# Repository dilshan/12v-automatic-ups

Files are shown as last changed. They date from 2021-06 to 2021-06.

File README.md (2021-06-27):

# 12V Uninterruptible Power Supply

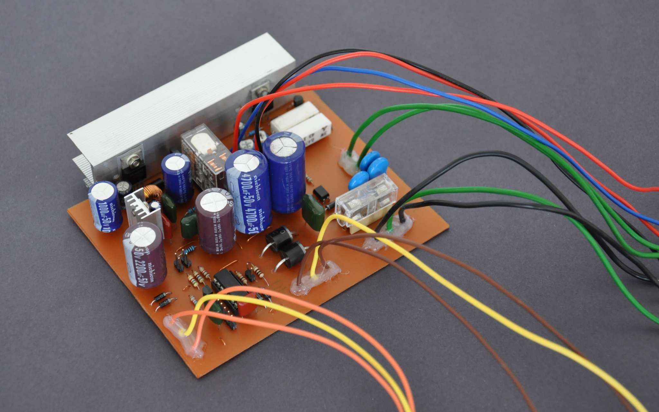
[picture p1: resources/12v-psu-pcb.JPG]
Prototype version of 12V UPS system


This 12V uninterruptible power supply initially designs to drive my fiber optic modem/router. The key reason to build this power supply is to get continuous internet and phone connection during power failures. Core components of this power supply are a constant voltage charger, 12V DC power supply, AC line monitoring unit, and 12V high capacity sealed lead-acid battery. The entire system designs using locally available components.

The charging circuit of this system builds around using the popular *[LM350](https://www.ti.com/lit/ds/snvs772b/snvs772b.pdf)* voltage regulator. This regulator calibrates to provide both 14.4V fast charging and 13.6V trickle charging. Based on the condition of the battery, the MCU will determine the appropriate charging mode.

At the online state, the *[LM2576-12](https://www.ti.com/lit/ds/symlink/lm2576.pdf)* switching regulator provides 12V output to the driving system. (in my arrangement, a fiber optic router).

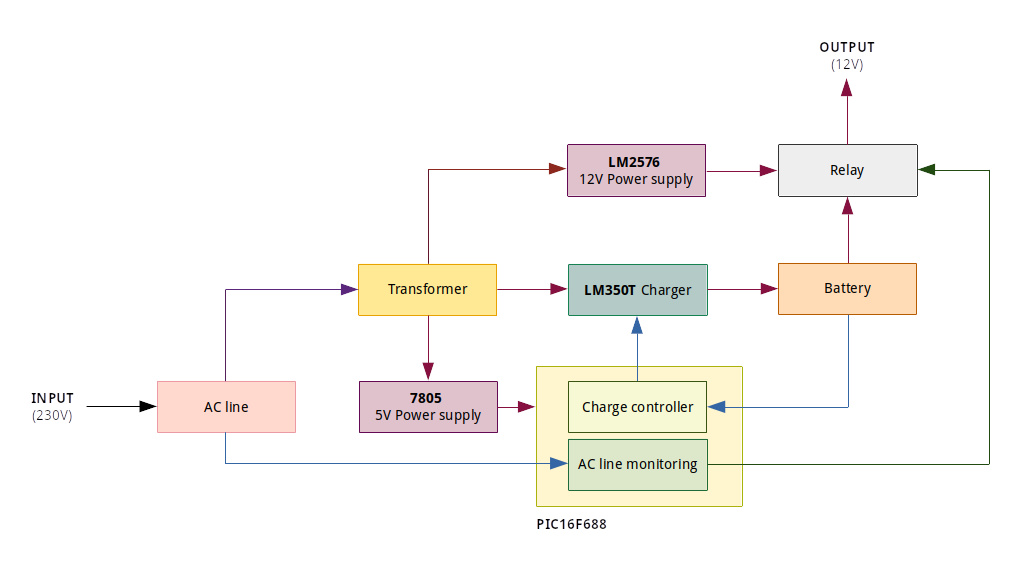
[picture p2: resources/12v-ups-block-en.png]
Block diagram of the UPS system


The *[PIC16F688](http://ww1.microchip.com/downloads/en/devicedoc/41203d.pdf)* MCU monitors the AC line and battery to controls the output voltage of the *LM350* regulator and the output relay. The firmware of this MCU written using the *[Microchip XC8](https://www.microchip.com/en-us/development-tools-tools-and-software/mplab-xc-compilers)* compiler, and all the source code and configuration files are available to [download](https://github.com/dilshan/12v-automatic-ups/releases) in this project repository.

The sealed 12V lead-acid battery is the most crucial component of this unit. 12V, 9Ah battery is the most recommended for this system. At the time of this writing, this battery cost around Rs. 3500 (US$ 17.60), and I bought it from a local online store.

In online mode, this system provides 12V output. In offline mode, if it has a fully charged battery, it delivers an output of 12.5V.

This uninterruptible power supply is suitable for appliances that need 12V - 13V input with a maximum of 2A current. With the configuration described above, this system continued to power my *[Huawei HG8245H5](https://carrier.huawei.com/en/products/fixed-network/access/cpe/h-series-products/hg8245h)* fiber optic router for more than 7 hours.

This power supply unit is an open hardware project. All the [schematic](https://github.com/dilshan/12v-automatic-ups/blob/main/design/ups-12v.pdf), [KiCAD PCB design files](https://github.com/dilshan/12v-automatic-ups/tree/main/design), [firmware source codes](https://github.com/dilshan/12v-automatic-ups/tree/main/firmware), and [compiled binaries](https://github.com/dilshan/12v-automatic-ups/releases) are available to download in this repository.

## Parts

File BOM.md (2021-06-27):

## Bill of materials

| Designator | Value | Package | Quantity | Notes |
|---|---|---|---|---|
| C1 | 10μF / 50V | | 1 | |
| C2, C13 | 4700μF / 50V | | 2 | |
| C3, C14 | 2200μF / 50V | | 2 | |
| C4, C5, C8, C9, C10 | 0.1μF | | 5 | Polyester film capacitor |
| C6 | 100μF / 50V | | 1 | |
| C7, C15 | 1000μF / 50V | | 2 | |
| C11 | 33MFD / 16V | | 1 | |
| C12 | 0.22μF | | 1 | Polyester film capacitor |
| D1, D4, D12 | 1N4004 | | 3 | This can be replaced with 1N4007 |
| D10, D13, D14 | 1N4007 | | 3 | |
| D2, D5 | 1N5819 | | 1 | |
| D3 | 1N5399 | | 1 | |
| D11 | 1N5822 | | 1 | |
| D7, D8 | 6A10 | | 2 | |
| D6 | 5mm RED LED | | 1 | |
| D9 | 5mm GREEN LED | | 1 | |
| R2, R4 | 0.47Ω | 22mm Power resistor | 2 | 5W Ceramic cement resistor |
| R3 | 22.0KΩ | | 1 | 1% Metal film resistor |
| R5, R10, R17 | 0Ω | | 3 | |
| R6 | 100Ω | | 1 | |
| R7 | 270.0Ω | | 1 | 1% Metal film resistor |
| R8 | 680.0Ω | | 1 | 1% Metal film resistor |
| R9, R16 | 10KΩ | | 2 | |
| R11, R14 | 560Ω | | 2 | |
| R12 | 220KΩ | | 1 | |
| R13 | 5.6KΩ | | 1 | |
| R15 | 1MΩ | | 1 | |
| R18 | 1KΩ | | 1 | |
| RV1 | 10KΩ | RM-065 | 1 | |
| RV2 | 5KΩ | RM-065 | 1 | |
| RV3 | 2KΩ | RM-065 | 1 | |
| L1 | 100μH | | 1 | 13.0mm Toroid inductor |
| RV4, RV5, RV6 | 7D471K | | 3 | Varistor |
| RL1 | OMRON G2R-2 12VDC | | 1 | |
| F1 | 20mm Fuse holder | | 1 | Include 3A/230V fuse |
| NE1 | 230V Neon lamp | | 1 | |
| J3 | 5-pin 2.54mm Pin header | | 1 | |
| J6 | 2-pin 2.54mm Pin header | | 1 | |
| Q1 | BC547 | TO-92 | 1 | |
| Q2 | BC548 | TO-92 | 1 | |
| Q3 | BD135 | TO-126 | 1 | |
| U1 | LM350T | TO-220 | 1 | |
| U2 | PIC16F688 | DIP-14 | 1 | |
| U3 | PC817 | DIP-4 | 1 | |
| U4 | LM2576T-12 | TO-220-5 | 1 | |
| U5 | LM7805 | TO-220 | 1 | |
| | Step down transformer; Primary: 230V Secondary: 15V × 2 (5A), 12V × 2 (500mA)  | | 1 | |
| | 12V, 9Ah Sealed lead acid battery | | 1 | |

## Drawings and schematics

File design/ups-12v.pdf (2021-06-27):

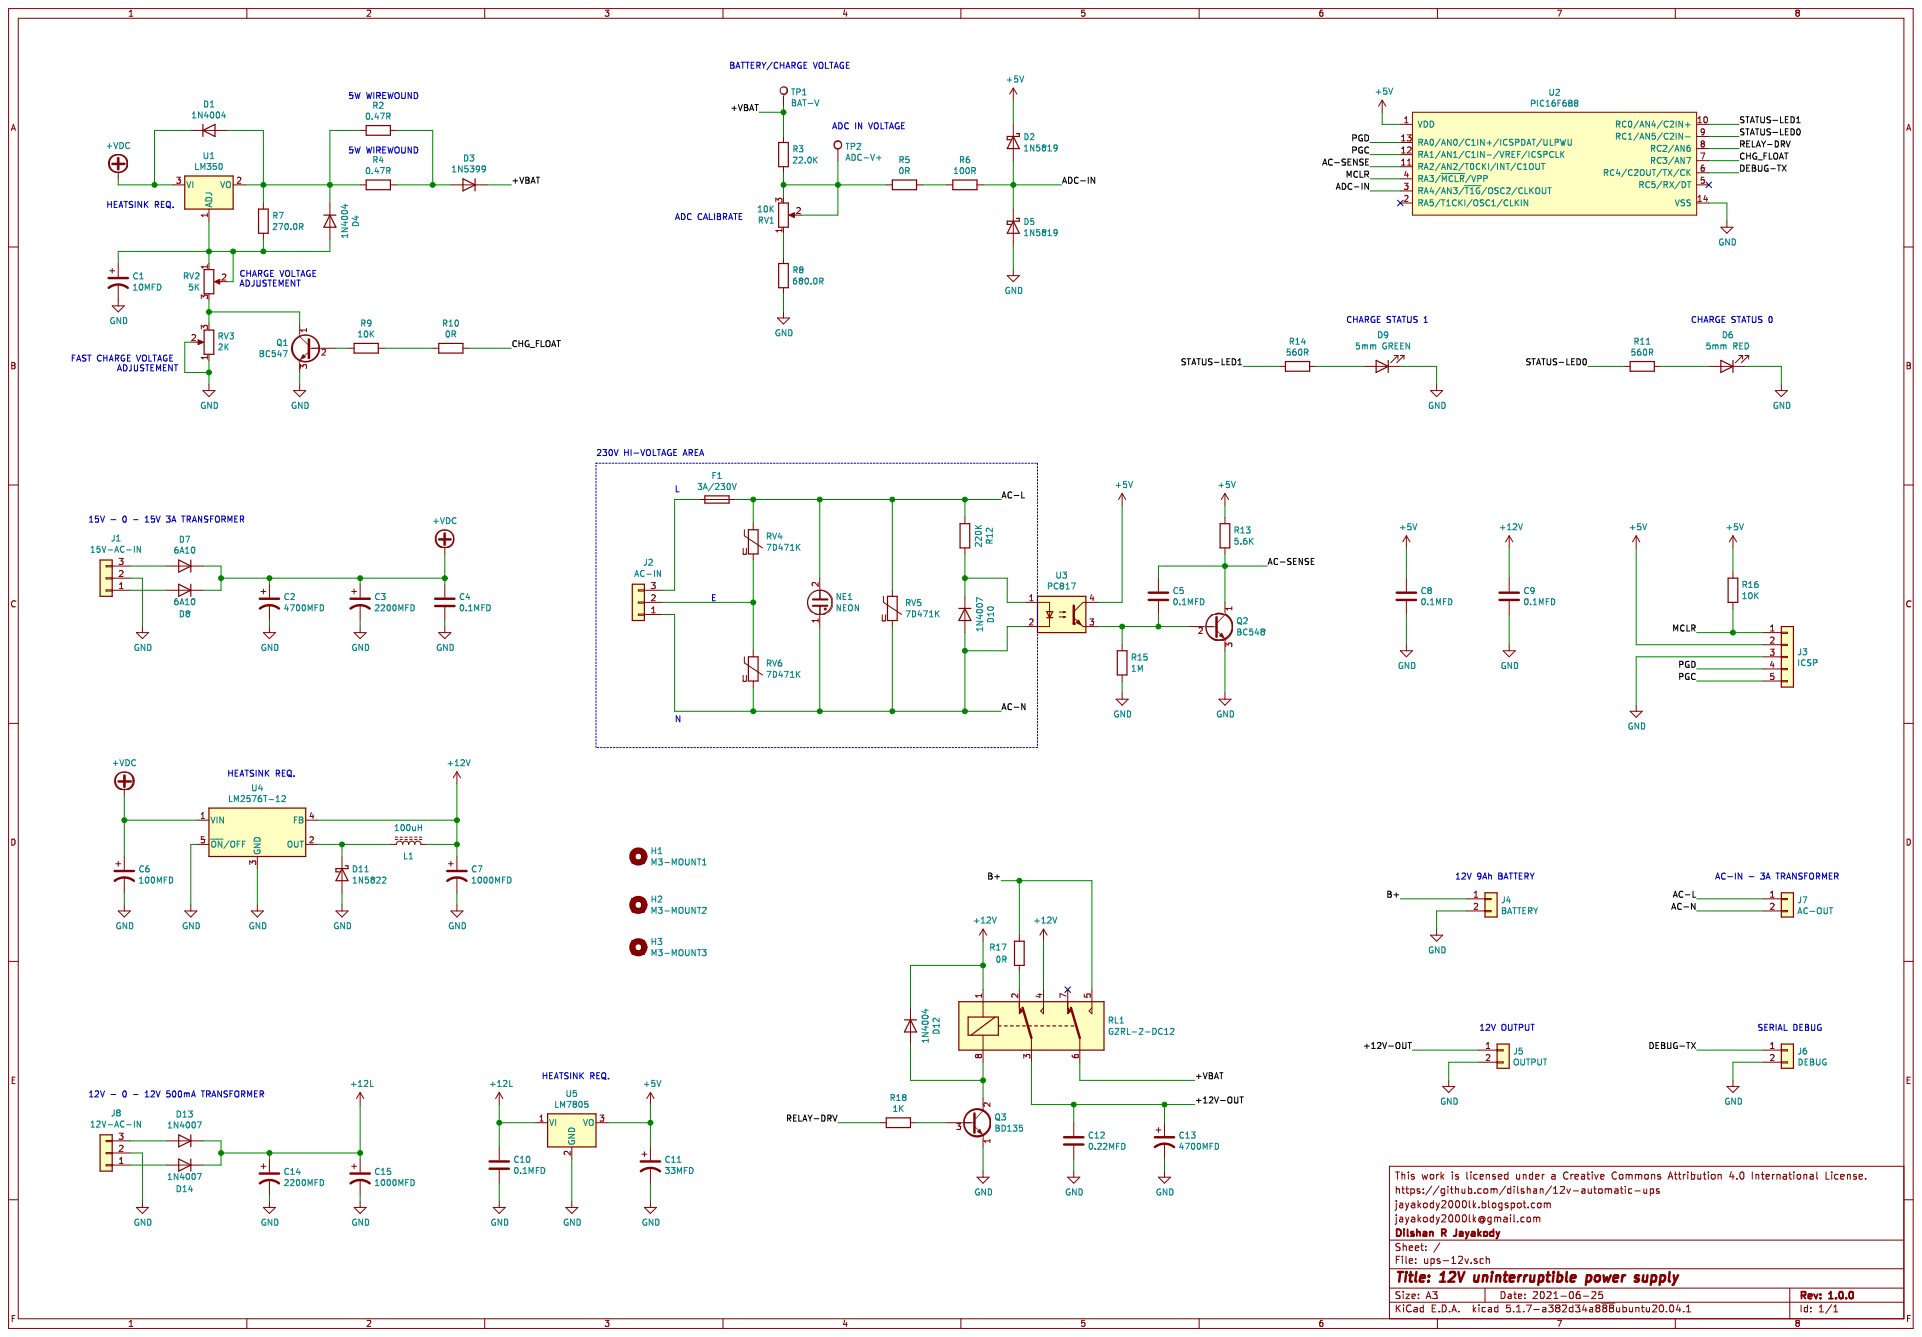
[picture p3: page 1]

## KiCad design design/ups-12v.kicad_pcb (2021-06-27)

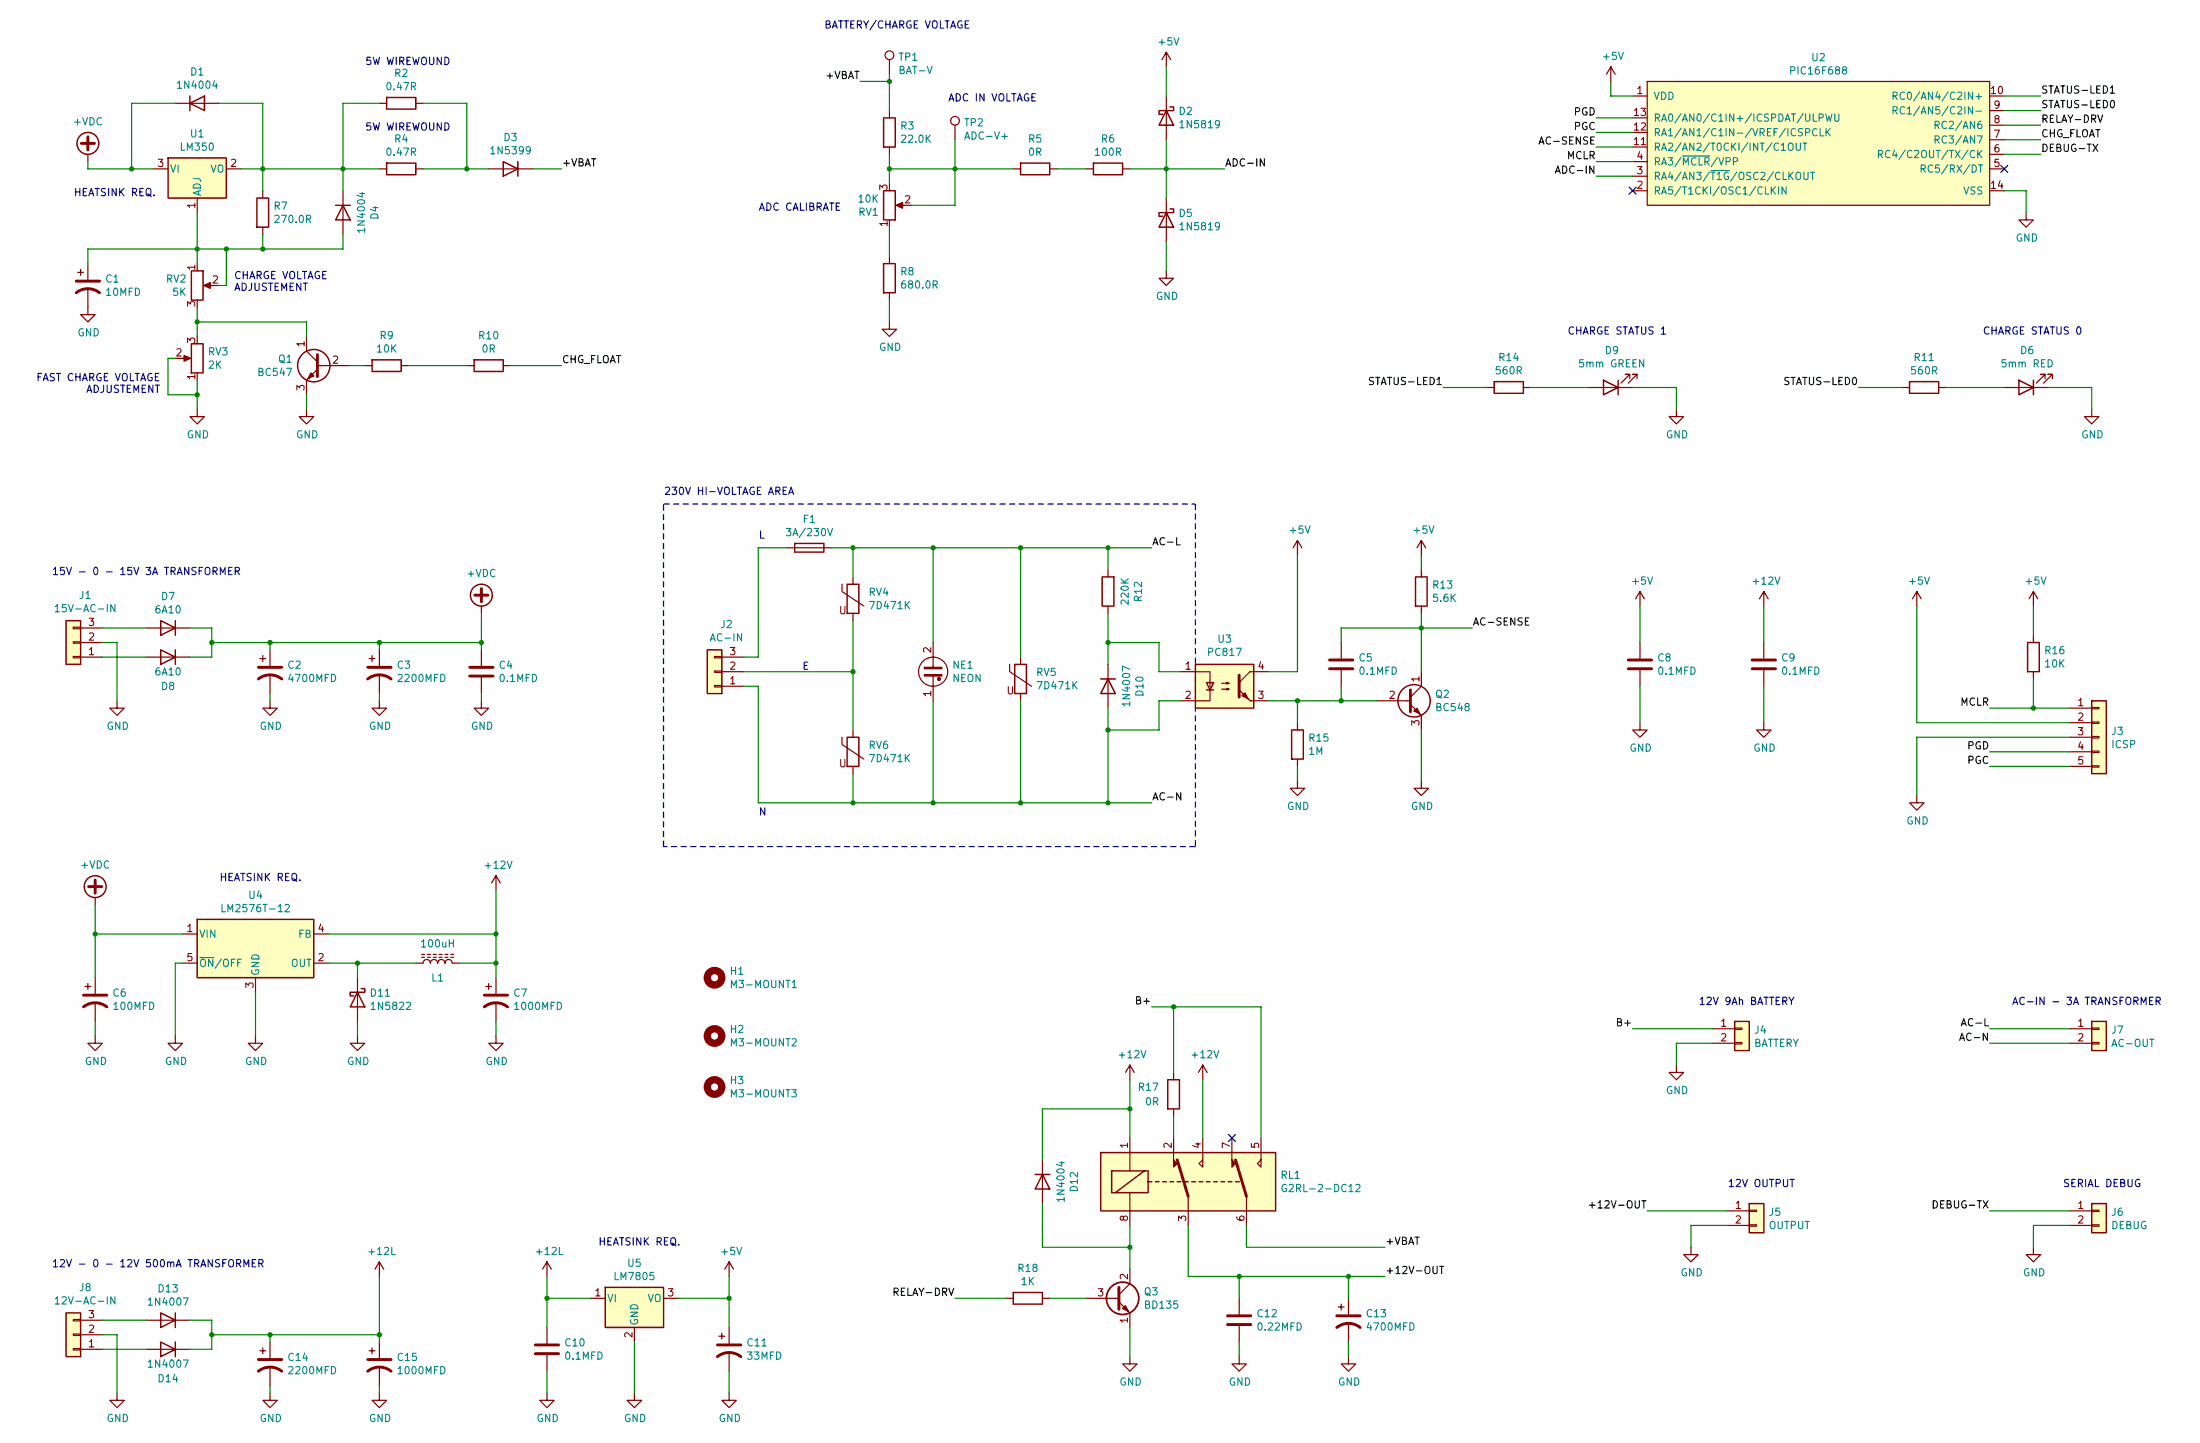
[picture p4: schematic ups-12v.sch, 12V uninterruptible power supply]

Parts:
C1: 10MFD; CP_Radial_D5.0mm_P2.00mm
C2, C13: 4700MFD; CP_Radial_D18.0mm_P7.50mm
C3, C14: 2200MFD; CP_Radial_D16.0mm_P7.50mm
C4, C5, C8, C9, C10: 0.1MFD; C_Disc_D10.5mm_W5.0mm_P7.50mm
C6: 100MFD; CP_Radial_D6.3mm_P2.50mm
C7, C15: 1000MFD; CP_Radial_D12.5mm_P5.00mm
C11: 33MFD; CP_Radial_D5.0mm_P2.50mm
C12: 0.22MFD; C_Disc_D11.0mm_W5.0mm_P10.00mm
D1, D4, D12: 1N4004; D_DO-41_SOD81_P10.16mm_Horizontal
D2, D5: 1N5819; D_DO-41_SOD81_P10.16mm_Horizontal
D3: 1N5399; D_DO-41_SOD81_P10.16mm_Horizontal
D6: 5mm RED; PinHeader_1x02_P2.54mm_Vertical
D7, D8: 6A10; D_P600_R-6_P20.00mm_Horizontal
D9: 5mm GREEN; PinHeader_1x02_P2.54mm_Vertical
D10, D13, D14: 1N4007; D_DO-41_SOD81_P10.16mm_Horizontal
D11: 1N5822; D_DO-201AD_P15.24mm_Horizontal
F1: 3A/230V; Fuseholder_Cylinder-5x20mm_Schurter_0031_8201_Horizontal_Op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
H1: M3-MOUNT1; MountingHole_3.2mm_M3
H2: M3-MOUNT2; MountingHole_3.2mm_M3
H3: M3-MOUNT3; MountingHole_3.2mm_M3
J1: 15V-AC-IN; Molex_Sabre_43160-0103_1x03_P7.49mm_Vertical
J2: AC-IN; Molex_Sabre_43160-0103_1x03_P7.49mm_Vertical
J3: ICSP; PinHeader_1x05_P2.54mm_Vertical
J4: BATTERY; Molex_Sabre_43160-0102_1x02_P7.49mm_Vertical
J5: OUTPUT; Molex_Sabre_43160-0102_1x02_P7.49mm_Vertical
J6: DEBUG; PinHeader_1x02_P2.54mm_Vertical
J7: AC-OUT; Molex_Sabre_43160-0102_1x02_P7.49mm_Vertical
J8: 12V-AC-IN; Molex_Sabre_43160-0103_1x03_P7.49mm_Vertical
L1: 100uH; L_Toroid_Vertical_L13.0mm_W6.5mm_P5.60mm
NE1: NEON; Fuse_Bourns_MF-RG300
Q1: BC547; TO-92_HandSolder
Q2: BC548; TO-92_HandSolder
Q3: BD135; TO-126-3_Vertical
R2, R4: 0.47R; R_Axial_Power_L25.0mm_W6.4mm_P27.94mm
R3: 22.0K; R_Axial_DIN0207_L6.3mm_D2.5mm_P10.16mm_Horizontal
R5: 0R; R_Axial_DIN0207_L6.3mm_D2.5mm_P15.24mm_Horizontal
R6: 100R; R_Axial_DIN0207_L6.3mm_D2.5mm_P15.24mm_Horizontal
R7: 270.0R; R_Axial_DIN0207_L6.3mm_D2.5mm_P10.16mm_Horizontal
R8: 680.0R; R_Axial_DIN0207_L6.3mm_D2.5mm_P10.16mm_Horizontal
R9, R16: 10K; R_Axial_DIN0207_L6.3mm_D2.5mm_P10.16mm_Horizontal
R10, R17: 0R; R_Axial_DIN0207_L6.3mm_D2.5mm_P10.16mm_Horizontal
R11, R14: 560R; R_Axial_DIN0207_L6.3mm_D2.5mm_P10.16mm_Horizontal
R12: 220K; R_Axial_DIN0207_L6.3mm_D2.5mm_P10.16mm_Horizontal
R13: 5.6K; R_Axial_DIN0207_L6.3mm_D2.5mm_P10.16mm_Horizontal
R15: 1M; R_Axial_DIN0207_L6.3mm_D2.5mm_P10.16mm_Horizontal
R18: 1K; R_Axial_DIN0207_L6.3mm_D2.5mm_P10.16mm_Horizontal
RL1: G2RL-2-DC12; Relay_DPDT_Omron_G2RL
RV1: 10K; Potentiometer_Runtron_RM-065_Vertical
RV2: 5K; Potentiometer_Runtron_RM-065_Vertical
RV3: 2K; Potentiometer_Runtron_RM-065_Vertical
RV4, RV5, RV6: 7D471K; RV_Disc_D9mm_W4mm_P5mm
TP1: BAT-V; TestPoint_Plated_Hole_D2.0mm
TP2: ADC-V+; TestPoint_Plated_Hole_D2.0mm
U1: LM350; TO-220-3_Vertical
U2: PIC16F688; DIP-14_W7.62mm_LongPads
U3: PC817; DIP-4_W7.62mm
U4: LM2576T-12; TO-220-5_Vertical
U5: LM7805; TO-220-3_Vertical

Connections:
+5V: C8.1, C11.1, D2.1 (K), J3.2, R13.1, R16.1, U2.1 (VDD), U3.4, U5.3 (VO)
+12L: C10.1, C14.1, C15.1, D13.1 (K), D14.1 (K), U5.1 (VI)
+12V: C7.1, C9.1, D12.1 (K), L1.2, RL1.1, RL1.4, U4.4 (FB)
+VDC: C2.1, C3.1, C4.1, C6.1, D1.1 (K), D7.1 (K), D8.1 (K), U1.3 (VI), U4.1 (VIN)
/+12V-OUT: C12.1, C13.1, J5.1, RL1.3
/+VBAT: D3.1 (K), R3.1, RL1.6, TP1.1
/AC-L: F1.1, J7.1, NE1.2, R12.2, RV4.1, RV5.1
/AC-N: D10.2 (A), J2.1, J7.2, NE1.1, RV5.2, RV6.2, U3.2
/AC-SENSE: C5.1, Q2.1 (C), R13.2, U2.11 (RA2/AN2/T0CKI/INT/C1OUT)
/ADC-IN: D2.2 (A), D5.1 (K), R6.1, U2.3 (RA4/AN3/~T1G~/OSC2/CLKOUT)
/B+: J4.1, R17.1, RL1.5
/CHG_FLOAT: R10.1, U2.7 (RC3/AN7)
/DEBUG-TX: J6.1, U2.6 (RC4/C2OUT/TX/CK)
/MCLR: J3.1, R16.2, U2.4 (RA3/~MCLR~/VPP)
/PGC: J3.5, U2.12 (RA1/AN1/C1IN-/VREF/ICSPCLK)
/PGD: J3.4, U2.13 (RA0/AN0/C1IN+/ICSPDAT/ULPWU)
/RELAY-DRV: R18.2, U2.8 (RC2/AN6)
/STATUS-LED0: R11.2, U2.9 (RC1/AN5/C2IN-)
/STATUS-LED1: R14.2, U2.10 (RC0/AN4/C2IN+)
GND: C1.2, C2.2, C3.2, C4.2, C6.2, C7.2, C8.2, C9.2, C10.2, C11.2, C12.2, C13.2, C14.2, C15.2, D5.2 (A), D6.1 (K), D9.1 (K), D11.2 (A), J1.2, J3.3, J4.2, J5.2, J6.2, J8.2, Q1.3 (E), Q2.3 (E), Q3.1 (E), R8.2, R15.2, RV3.1, RV3.2, U2.14 (VSS), U4.3 (GND), U4.5 (~ON~/OFF), U5.2 (GND)
unnamed: C1.1, D4.2 (A), R7.2, RV2.1, RV2.2, U1.1 (ADJ)
unnamed: C5.2, Q2.2 (B), R15.1, U3.3
unnamed: D1.2 (A), D4.1 (K), R2.2, R4.2, R7.1, U1.2 (VO)
unnamed: D3.2 (A), R2.1, R4.1
unnamed: D6.2 (A), R11.1
unnamed: D7.2 (A), J1.3
unnamed: D8.2 (A), J1.1
unnamed: D9.2 (A), R14.1
unnamed: D10.1 (K), R12.1, U3.1
unnamed: D11.1 (K), L1.1, U4.2 (OUT)
unnamed: D12.2 (A), Q3.2 (C), RL1.8
unnamed: D13.2 (A), J8.3
unnamed: D14.2 (A), J8.1
unnamed: F1.2, J2.3
unnamed: J2.2, RV4.2, RV6.1
unnamed: Q1.1 (C), RV2.3, RV3.3
unnamed: Q1.2 (B), R9.2
unnamed: Q3.3 (B), R18.1
unnamed: R3.2, R5.2, RV1.2, RV1.3, TP2.1
unnamed: R5.1, R6.2
unnamed: R8.1, RV1.1
unnamed: R9.1, R10.2
unnamed: R17.2, RL1.2

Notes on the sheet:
CHARGE VOLTAGE ADJUSTEMENT
FAST CHARGE VOLTAGE ADJUSTEMENT
ADC CALIBRATE
BATTERY/CHARGE VOLTAGE
ADC IN VOLTAGE
15V - 0 - 15V 3A TRANSFORMER
HEATSINK REQ.
CHARGE STATUS 0
CHARGE STATUS 1
12V 9Ah BATTERY
SERIAL DEBUG
12V OUTPUT
5W WIREWOUND
230V HI-VOLTAGE AREA
AC-IN - 3A TRANSFORMER
12V - 0 - 12V 500mA TRANSFORMER

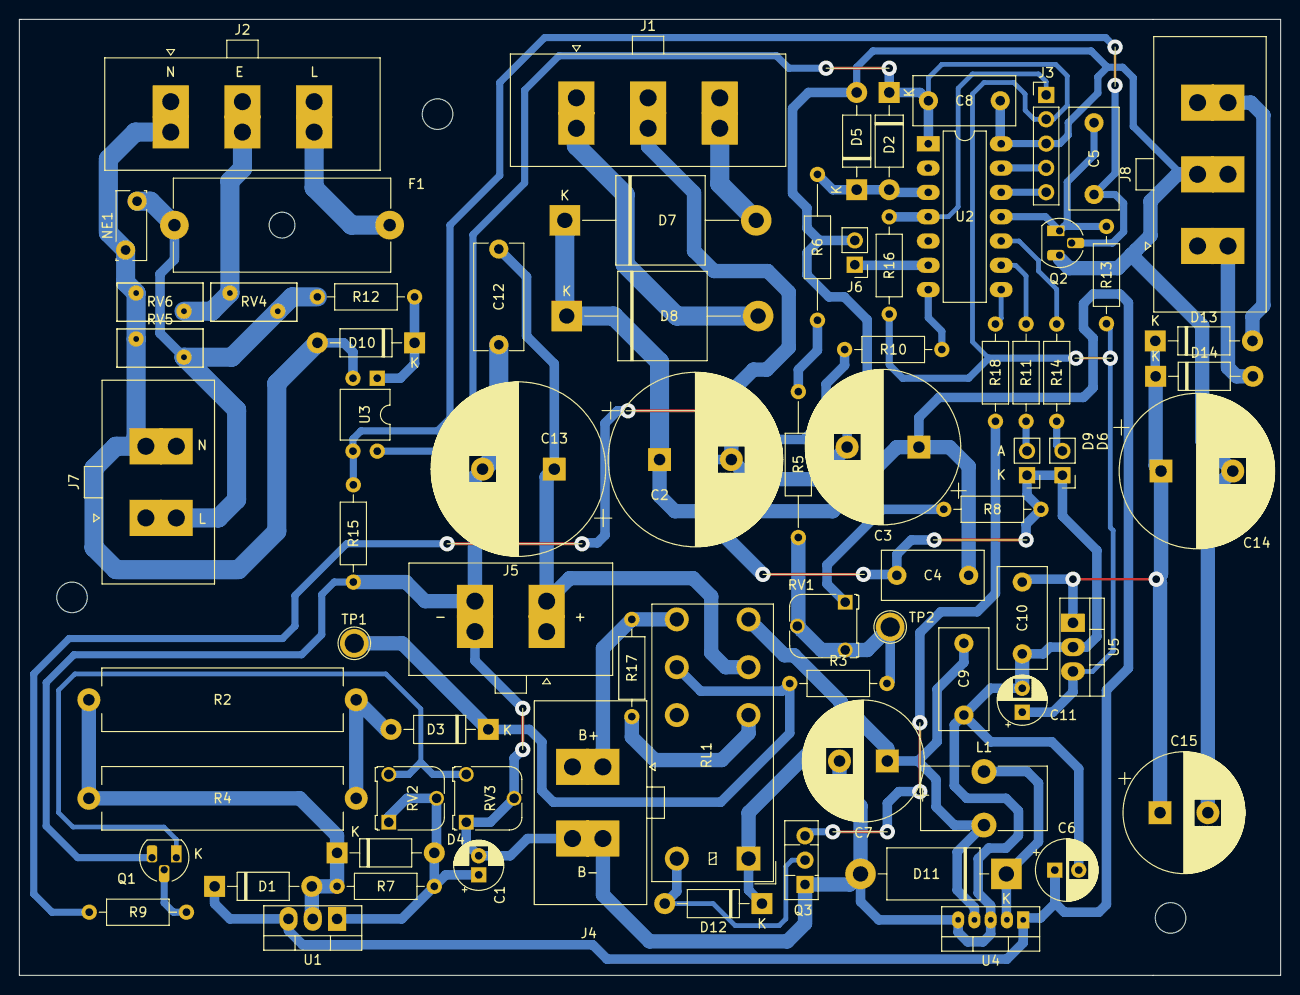
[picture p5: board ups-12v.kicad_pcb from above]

Board: 2 copper layers, 131.8 x 99.9 mm, 77 parts (0 on the bottom side), 43 nets.

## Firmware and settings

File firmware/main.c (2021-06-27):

/*******************************************************************************
 * Copyright (c) 2021 Dilshan R Jayakody. [jayakody2000lk@gmail.com]
 *
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
 * THE SOFTWARE IS PROVIDED "AS IS", WITHOUT WARRANTY OF ANY KIND, EXPRESS OR 
 * IMPLIED, INCLUDING BUT NOT LIMITED TO THE WARRANTIES OF MERCHANTABILITY, 
 * FITNESS FOR A PARTICULAR PURPOSE AND NONINFRINGEMENT. IN NO EVENT SHALL THE 
 * AUTHORS OR COPYRIGHT HOLDERS BE LIABLE FOR ANY CLAIM, DAMAGES OR OTHER 
 * LIABILITY, WHETHER IN AN ACTION OF CONTRACT, TORT OR OTHERWISE, ARISING FROM,
 * OUT OF OR IN CONNECTION WITH THE SOFTWARE OR THE USE OR OTHER DEALINGS IN 
 * THE SOFTWARE.
 ******************************************************************************/

#include <xc.h>

#include "config.h"
#include "main.h"

// Maximum voltage level is set to 16V, (16V * 10K)/(10K + 22K) = 5V
// 160 => 16V x 10 to avoid floating point calculations.
#define MAX_VOLTAGE 160

// Number of samples to normalize the ADC voltage readings.
#define ADC_SAMPLES 10

// Startup delay in 0.5 seconds unit. (3 => 3 x 0.5 = 1.5 seconds.)
#define STARTUP_DELAY   3

void main(void) 
{
    CLRWDT();
    WDTCON = 0x00;
    
    unsigned short retVal, normVal;
    unsigned long chrgVoltage;
    unsigned char normPos, blinkState;
    ChargeMode chargeMode;
    
    // Initialize variables to known state.
    normPos = 0;
    startupDelay = 0;
    isRelayActive = 0;
    blinkState = 0;
    chargeMode = CMODE_NONE;
    
    // Initialize MCU peripherals.
    initSystem();
    
    sendLog("Start\r\n");
    
    // Check line status and confirm AC is online.
    while((PORTA & 0x04) != 0x00)
    {
        // AC line status is offline, may be PSU is in middle of shutdown?
        __delay_ms(5);
    } 
    
    sendLog("AC Online\r\n");
    
    // Initiate TIMER1 with 0.5sec triggers.
    T1CON = 0x3D;
    
    // Wait until startup delay is expired...
    while(isRelayActive == 0)
    {
        __delay_ms(20);
    }
    
    // Startup delay is now expired, shutdown the TIMER1 and continue.
    sendLog("Delay Expired\r\n");    
    T1CON = 0x00;
    PIE1 &= 0xFE;
        
    // Cut-off battery and activate 12V supply from PSU.
    PORTC |= 0x04;
    
    // Enable edge interrupt on RA2 to detect AC power failures.
    INTCON &= 0xFD;
    INTCON |= 0x10; 
    
    sendLog("EXT-INT Enable\r\n");
    
    // Wait until charger get normalize.
    __delay_ms(100);
    
    sendLog("Service Start\r\n");
    
    // Main service loop.
    while(1)
    {                      
        normVal = 0;
        
        if(isRelayActive == 0)
        {
            // Power failure detected, reset the MCU.
            PORTC &= 0xFC; 
                    
            INTCON &= 0x7F; 
            T1CON = 0x00;
            PIE1 = 0x00;
            PIR1 = 0x00;
            
            WDTCON = 0x01;            
            while(1);
        }
        
        for(normPos = 0; normPos < ADC_SAMPLES; normPos++)
        {        
            // Get ADC reading from RA4(AN3) pin.
            retVal = getADC();

            // Convert ADC value to 10 x volts.
            chrgVoltage = ((unsigned long)MAX_VOLTAGE * (unsigned long)retVal)/(unsigned long)1023;      
            normVal += (unsigned short)chrgVoltage;
            
            // If battery is weak or dead, blink charge status LEDs.
            if(chargeMode == CMODE_DEAD)
            {
                if((++blinkState) >= 2)
                {
                    blinkState = 0;
                    PORTC ^= 0x03;
                }
            }
          
            __delay_ms(200);
        }
        
        // Get normalized ADC value.
        retVal = normVal / ADC_SAMPLES;        
        logVoltage(retVal);        
        
        if(retVal > 130)
        {
            // Battery is fully charged and switch on floating (slow) charge mode.
            PORTC &= 0xFE;
            PORTC |= 0x0A;
            chargeMode = CMODE_SLOW;
            sendLog("MODE: Float Charging\r\n");
        }
        else if((chargeMode == CMODE_SLOW) && (retVal >= 125))
        {
            // Battery is almost charged. Keep it in slow charge mode to avoid 
            // fluctuations in charge mode.
            PORTC &= 0xFE;
            PORTC |= 0x0A;
            sendLog("MODE: Float Charging [*]\r\n");
        }        
        else if(retVal < 80)
        {
            // May be the battery is bad? Try to slow charge the battery...            
            PORTC |= 0x08;
            chargeMode = CMODE_DEAD;
            sendLog("MODE: Dead Battery\r\n");
        }
        else
        {
            // Battery charge level is low and switch on fast charging mode.
            PORTC &= 0xF5;
            PORTC |= 0x01;
            chargeMode = CMODE_FAST;
            sendLog("MODE: Fast Charging\r\n");
        }
    }
    
    return;
}

void __interrupt() isrMain(void)
{
    // TIMER1 interrupt handler.
    if(PIR1 & 0x01)
    {                      
        if((++startupDelay) >= STARTUP_DELAY)
        {
            // Startup delay is expired. Disable the TIMER1.
            PIE1 &= 0xFE;
            isRelayActive = 1;
        }
        
        // Reset TIMER1 flags and counter registers.
        TMR1H = 0;
        TMR1L = 0;
        PIR1 &= 0xFE;        
    }
    
    // External interrupt handler.
    if(INTCON & 0x02)
    {
        // Power failure (Raising edge) is detected on AC line status input.
        // Cut-off 12V supply and set battery output.
        PORTC &= 0xFB;
        isRelayActive = 0;
        INTCON &= 0xFD;
    }
}

void initSystem()
{
    // RA2 - AC mains status input.
    // RA4(AN3) - Battery voltage sense (ADC) input. 
    // RA3(MCLR) - Reset (ICP).
    // RC0 - Charge status LED - Fast charge / Dead.
    // RC1 - Charge status LED - Float charge / Dead.
    // RC2 - Mains / Battery selector relay.
    // RC3 - Standby charge control (LM350T - ADJ).    
    
    CMCON0 = 0x07;
    ANSEL = 0x08;
    ADCON0 = 0x8D;
    ADCON1 = 0x00;
    VRCON = 0x00;
    
    // System starts with slow charging mode.
    TRISC = 0x30;
    PORTC = 0x38;
    
    TRISA = 0x14;
    PORTA = 0x00;
    
    // baud rate is set to 1200; Let (4000000 - 9600*64)/(1200*64) = 51
    SPBRG = 51;   
    RCSTA = 0x90;
    TXSTA = 0x22;
        
    // Reset TIMER1 counters.
    TMR1H = 0;
    TMR1L = 0;
    
    // Enable TIMER1 and external interrupts.
    OPTION_REG |= 0x40;
    INTCON = 0xC0;
    PIE1 = 0x01;
    PIR1 = 0x00;
}

unsigned short getADC()
{
    ADCON0 |= 0x02;    
    while(ADCON0 & 0x02);
    return (ADRESL + (ADRESH << 8));
}

void logVoltage(unsigned short voltage)
{
    char voltageOut[5];
    
    // Convert specified voltage into 5 digit string.
    voltageOut[4] = 0x00;
    voltageOut[3] = (voltage % 10) + 48;
    voltageOut[2] = ((voltage % 100)/10) + 48;
    voltageOut[1] = ((voltage % 1000)/100) + 48;
    voltageOut[0] = (voltage / 1000) + 48; 
    
    sendLog(voltageOut);
    sendLog("\r\n");
}

void sendLog(char* logData)
{
    while(*logData != 0)
    {
        // Wait for any pending transmissions.
        while(!TRMT);
        
        // Send next byte to the host terminal.
        TXREG = *logData;        
        logData++;
    }
}

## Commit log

2021-06-27 Initial version of 12V UPS design files and source codes.
    [ups-12v.kicad_pcb, ups-12v.sch]
2021-06-27 Fix typos in readme file and BOM file.
2021-06-27 Add image of prototype build into the readme file.

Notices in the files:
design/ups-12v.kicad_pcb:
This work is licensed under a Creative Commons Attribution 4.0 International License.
